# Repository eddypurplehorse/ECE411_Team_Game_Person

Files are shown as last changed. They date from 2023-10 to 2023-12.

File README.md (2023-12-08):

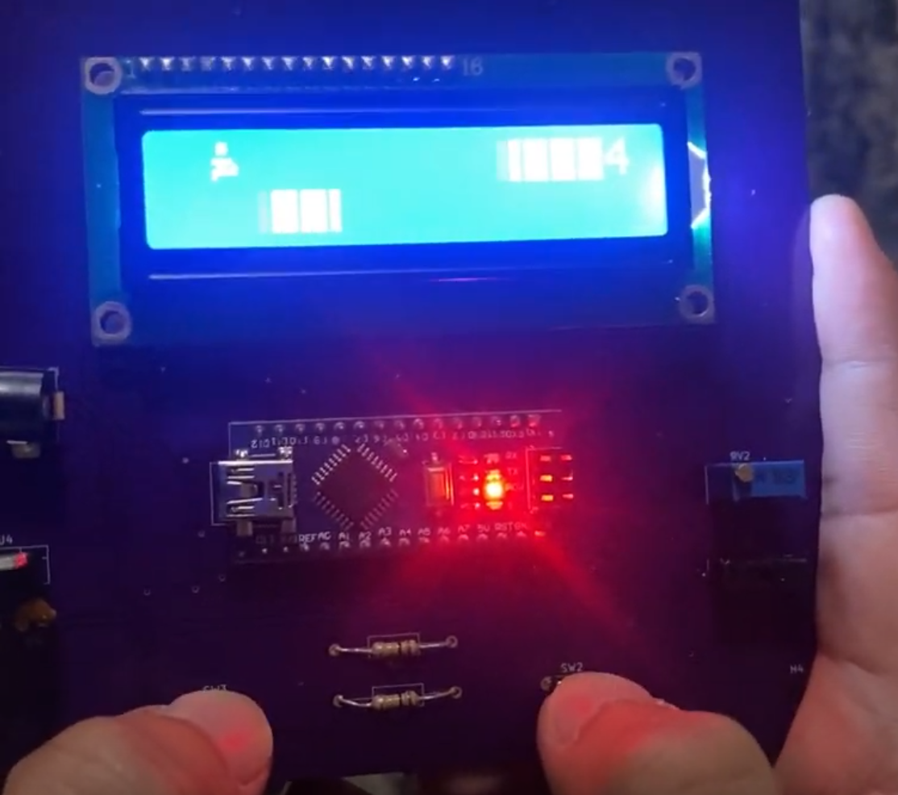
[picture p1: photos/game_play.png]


# ECE 411 Team 10 - Project LCD GAME 

Members:
* Alexandra G
* Eduardo S
* Paul C
* Sam H

## Project
A cheap and fun portable game!

## License
This project is licensed under the term of the GNU General Public V3.0 License  
and the CERN Open Hardware License V2.0 License

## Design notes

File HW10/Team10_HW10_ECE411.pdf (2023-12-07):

TEAM 10: Alexandrea G, Eduardo S, Paul C, Sam H email: guzman8@pdx.edu, eduardo8@pdx.edu, chupaul@pdx.edu, hossein2@pdx.edu

HW 10: Test Plan | Prof. Andrew Greenberg
ECE 411: Industry Design Processes | 12/06/2023

Part 1:

Unit Tests

1. Power Supply Checks:
- Test that the 9V battery outputs a consistent 9V.
- Verify that the 9V-to-5V voltage regulator outputs a stable 5V supply.
- Measure the current draw from the power supply to ensure it's within expected limits.
2. Microcontroller (ATmega328p) Tests:
- Upload a simple sketch to blink an LED to ensure the microcontroller is functioning.
- Test all I/O pins for correct operation by toggling them high and low.
3. LCD Tests:
- Test the LCD display initialization and confirm that characters are correctly displayed.
- Verify SPI bus protocol communication between ATmega328p and the LCD.
- Validate contrast and clear display functions of the LCD.
4. User Interface Components:
- Test that the 10k linear potentiometer properly adjusts the LCD backlight across the entire range.
- Confirm that each push button registers a press and causes an interrupt in the microcontroller.
5. Physical Structure:
- Inspect the housing for structural integrity and fit for the components.
- Ensure the printed circuit board has no shorts or openings and that all solder joints are secure.

Verification Tests

1. Power Connectivity:
- Confirm that the power switch transitions power without interrupting the circuit.
2. Display Operation:
- Test the LCD for correct display of game information upon microcontroller command.
- Verify that the potentiometer effectively dims the LCD backlight.
3. User Interaction:
- Validate that the 'Up' button increases a value on the display, such as score or time.
- Ensure that the 'Down' button decreases a value on the display.
4. Gameplay Experience:
- Simulate a game scenario and verify that all components interact as expected.
- Check that the actuator (LCD) updates in real-time with user input.

Validation Tests

1. System Requirements:
- Validate that the entire system operates continuously under battery power for a set duration.
- Confirm that the user can interact with the game through push buttons and receive visual feedback on the LCD.
- Ensure that the brightness adjustment feature meets the user's need for visibility under different lighting conditions.
2. Performance and Reliability:
- Test that the system can be operated multiple times without failure.
- Validate that the game reacts within acceptable time limits to user input.
3. Aesthetic and Protective Housing:
- Verify that the housing meets the aesthetic design specifications.

Part 2:

Test 1:
Test Author: Alexandrea G, and Sam H.
Test Case Name: | Power Output Verification Test | Test ID #: | PO-VT1
Description: | This test verifies the output of the 9V battery and the 5V regulator output under normal conditions using a multimeter. | Type: | □white box ☑ black box □ ________

Tester Information
| Name of Tester: | Sam H. | Date: | 11/28/2023
| HW/SW Version: | V.1 | Time: | 4:50PM
| Setup: | Fully assembled game device with a 9V battery connected to the power input module and a multimeter set to measure DC voltage.
S T E P | Action | Expected Result | P A S S | F A I L | N / A | Comments
1 | Power up the device using the 9V battery. | LCD screen powers on with welcome message and microcontroller’s red led lights up. | ☑
2 | Measure the output voltage directly from the 9V battery. | The multimeter should read close to 9V, within a tolerance of ±0.5V for the battery output. | ☑
3 | Measure the output voltage from the 9V-to-5V voltage regulator. | The multimeter should read 5V, within a tolerance of ±0.25V for the regulator output. | ☑
4 | Measure the voltage at the power input pin of the microcontroller. | The multimeter should read 5V, within a tolerance of ±0.25V at the microcontroller power input. | ☑
5 | Measure the voltage at the power input of the LCD display. | The multimeter should read 5V, within a tolerance of ±0.25V at the LCD power input. | ☑
6 | Measure the voltage at the | The multimeter should show a variable voltage from 0 to 5V as ☑

| terminals of the 10k linear potentiometer. | the potentiometer is adjusted.
7 | Measure the voltage at the input of each push button when pressed. | The multimeter should read 5V at the push button terminals when pressed and 0V when not pressed. | ☑
| Overall test result: | | ☑ | Test passes 100%.

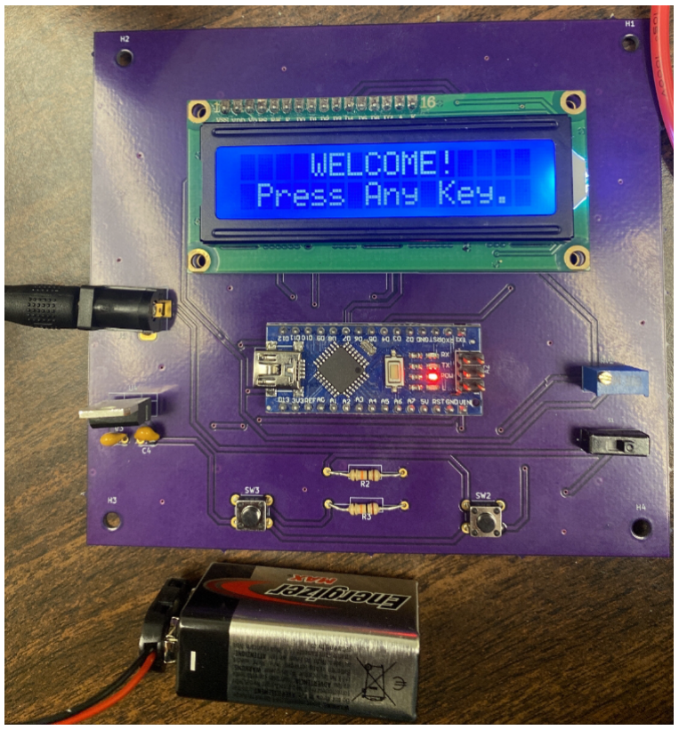
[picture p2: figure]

Figure 1: Test 1 passed.

Test 2:

Test Author: Paul C. and Eduardo S.
Test Case Name: | User Interface Functionality Test | Test ID #: | UI-FT1
Description: | This test verifies the User Interface functionality of the gaming device, specifically testing the LCD display and push-button inputs. | Type: | ☑white box □ black box □ ________

Tester Information
| Name of Tester: | Eduardo S. | Date: | 12/01/2023
| HW/SW Version: | V.1 | Time: | 10:00PM
| Setup: | Arduino Nano with attached LCD display and push buttons setup on the breadboard as per schematic. 9v Battery plugged in. Arduino Nano encoded with game.
S T E P | Action | Expected Result | P A S S | F A I L | N / A | Comments
1 | Power up the device using the 9V battery. | Device powers on without issues. | ☑
2 | Adjust the potentiometer to set the LCD backlight to mid-brightness. | Backlight brightness changes visibly. | ☑
3 | Press the 'Up' button to move the game character up. | Game character moved up on the LCD display. | ☑
4 | Press the 'Down' button to move the game character down. | Game character moved down on the LCD display. | ☑
5 | Check if the LCD updates correctly in response to button presses. | LCD consistently shows correct game character placement in response to button presses. | ☑
| Overall test result: | | ☑ | | | Test passes 100%. A video was recorded of this test being

performed and passing.

The video of the software working can be found here. (https://drive.google.com/file/d/1STEE0lARFS0cR7oybk-pXLPwNEp8A4RE/view?usp=drive_link)

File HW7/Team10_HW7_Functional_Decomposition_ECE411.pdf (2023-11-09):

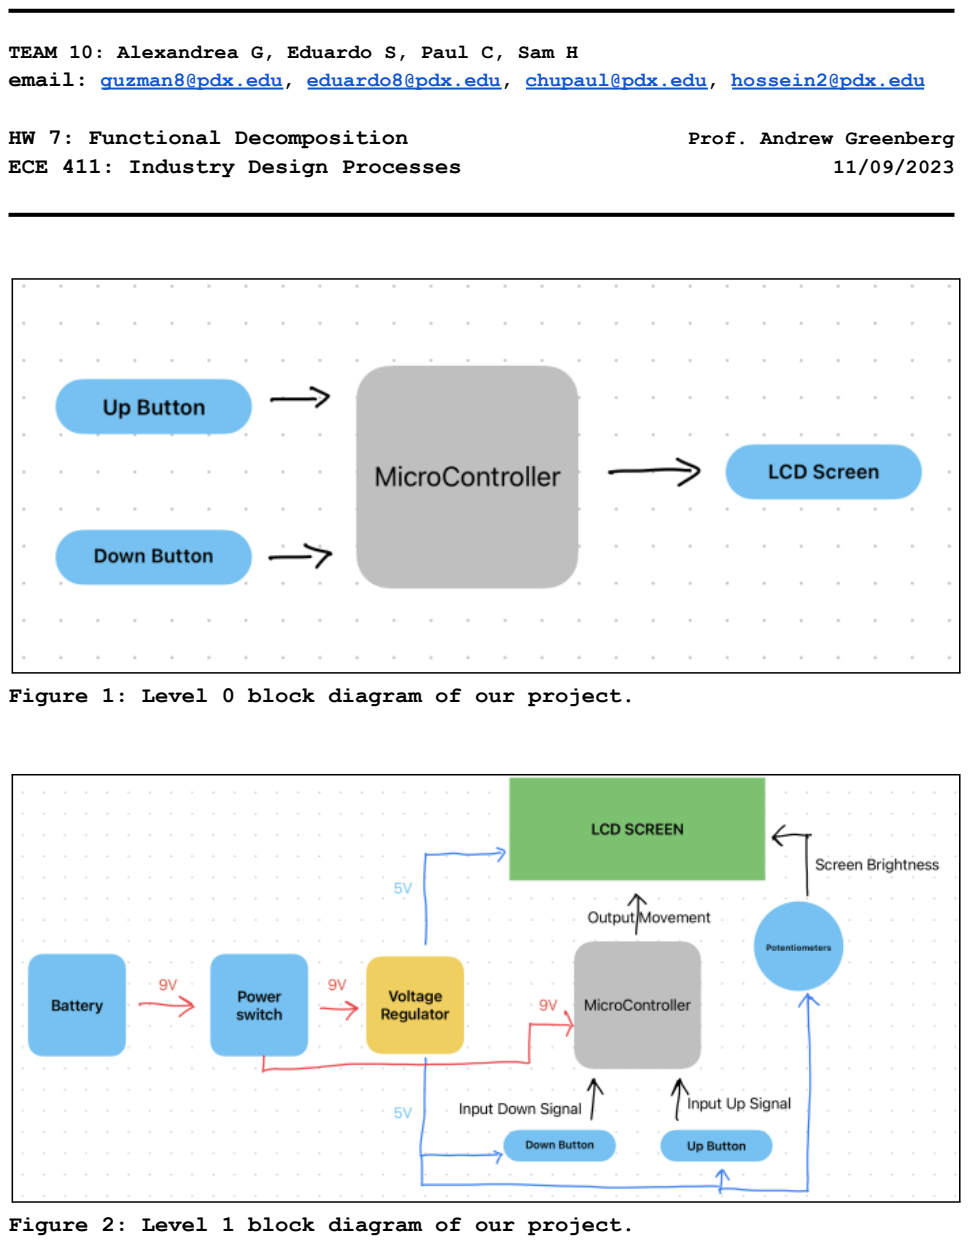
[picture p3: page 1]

TEAM 10: Alexandrea G, Eduardo S, Paul C, Sam H
email: guzman8@pdx.edu, eduardo8@pdx.edu, chupaul@pdx.edu, hossein2@pdx.edu
HW 7: Functional Decomposition | Prof. Andrew Greenberg
ECE 411: Industry Design Processes | 11/09/2023

Figure 1: Level 0 block diagram of our project.

Figure 2: Level 1 block diagram of our project.

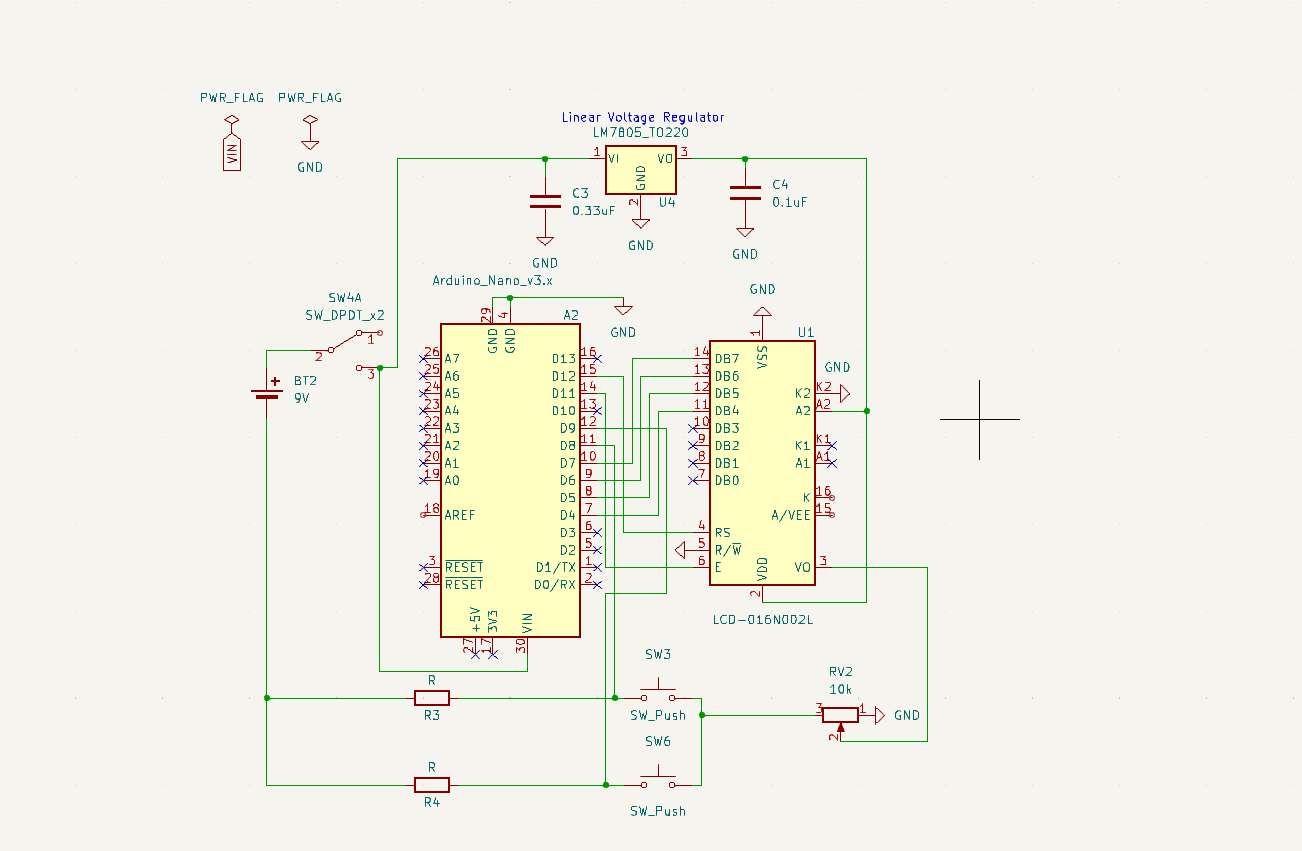
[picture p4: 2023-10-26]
photos/LCD_GAME_SCHEMATIC_V1.png

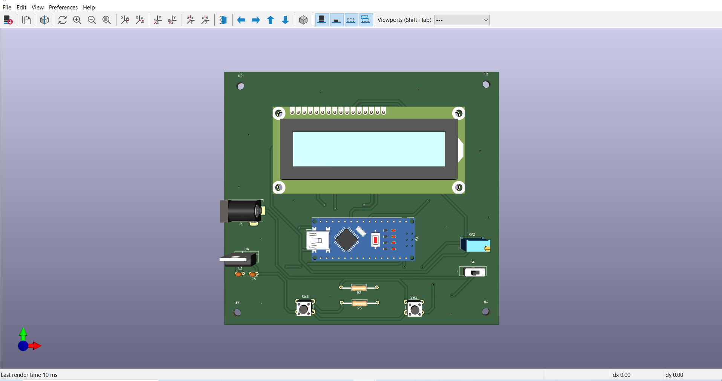
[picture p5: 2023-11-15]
kicad_schematic/V4_LCD_GAME_3D_MODLE_FINAL_VERSION.png

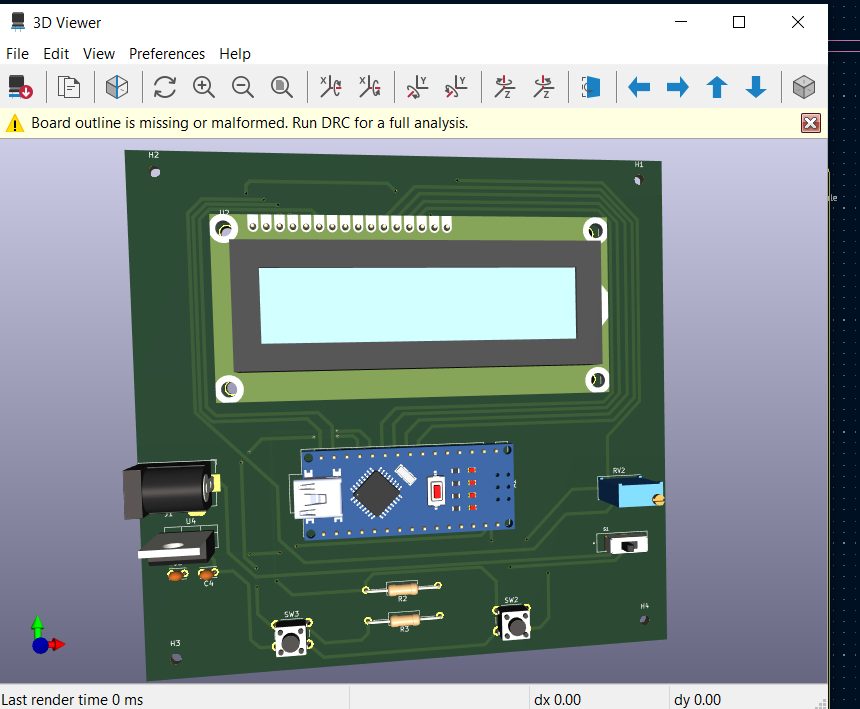
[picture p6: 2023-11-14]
kicad_schematic/V3_LCD_GAME_3D_MODLE.png

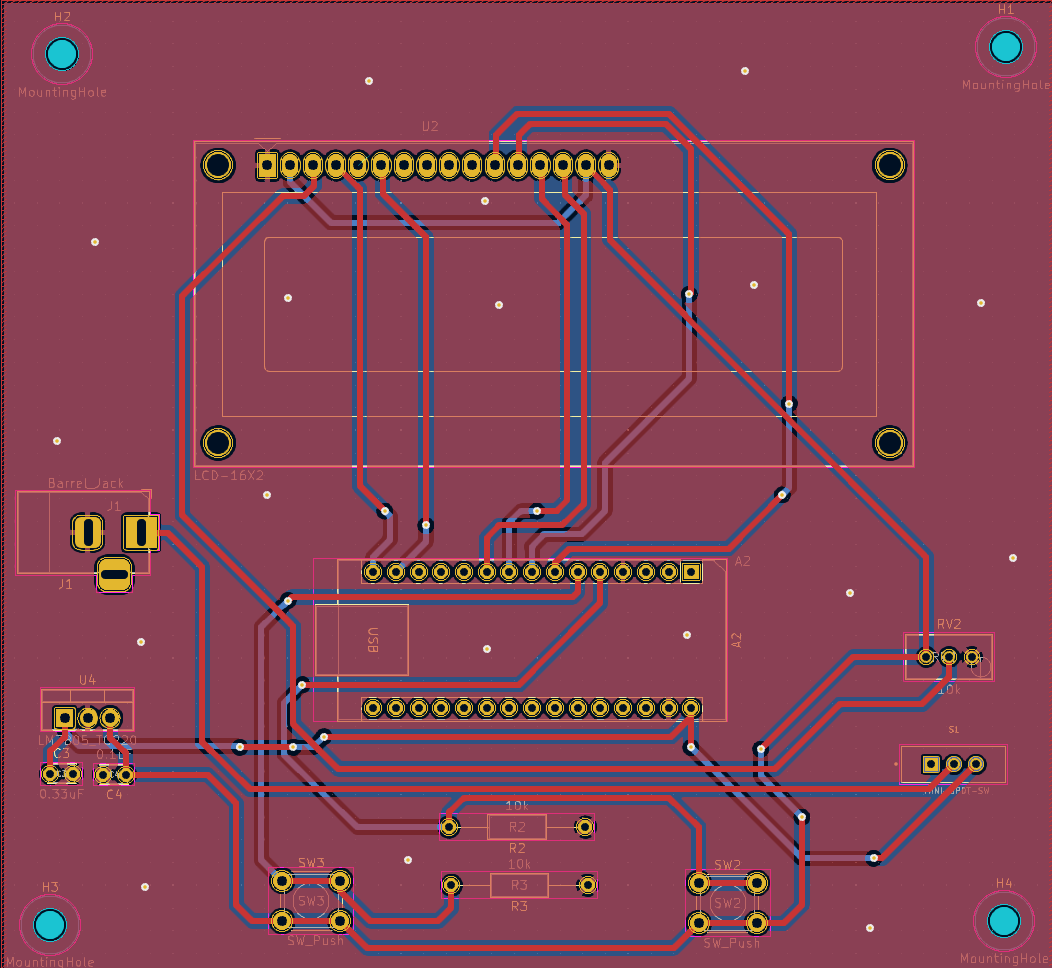
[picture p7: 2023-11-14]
kicad_schematic/V3_LCD_GAME_PCB.png

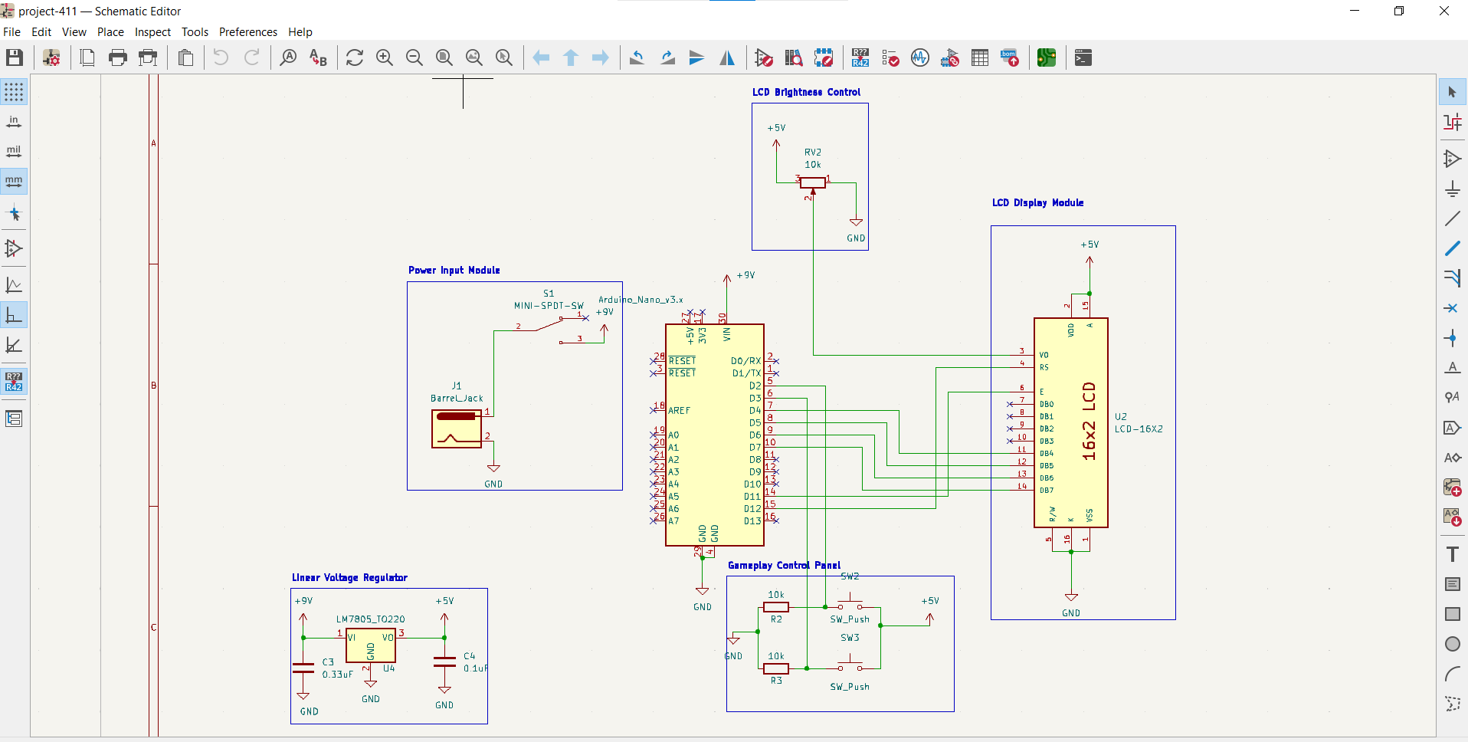
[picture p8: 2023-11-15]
kicad_schematic/V4_LCD_GAME_SCHEMATIC_FINAL_VERSION.png

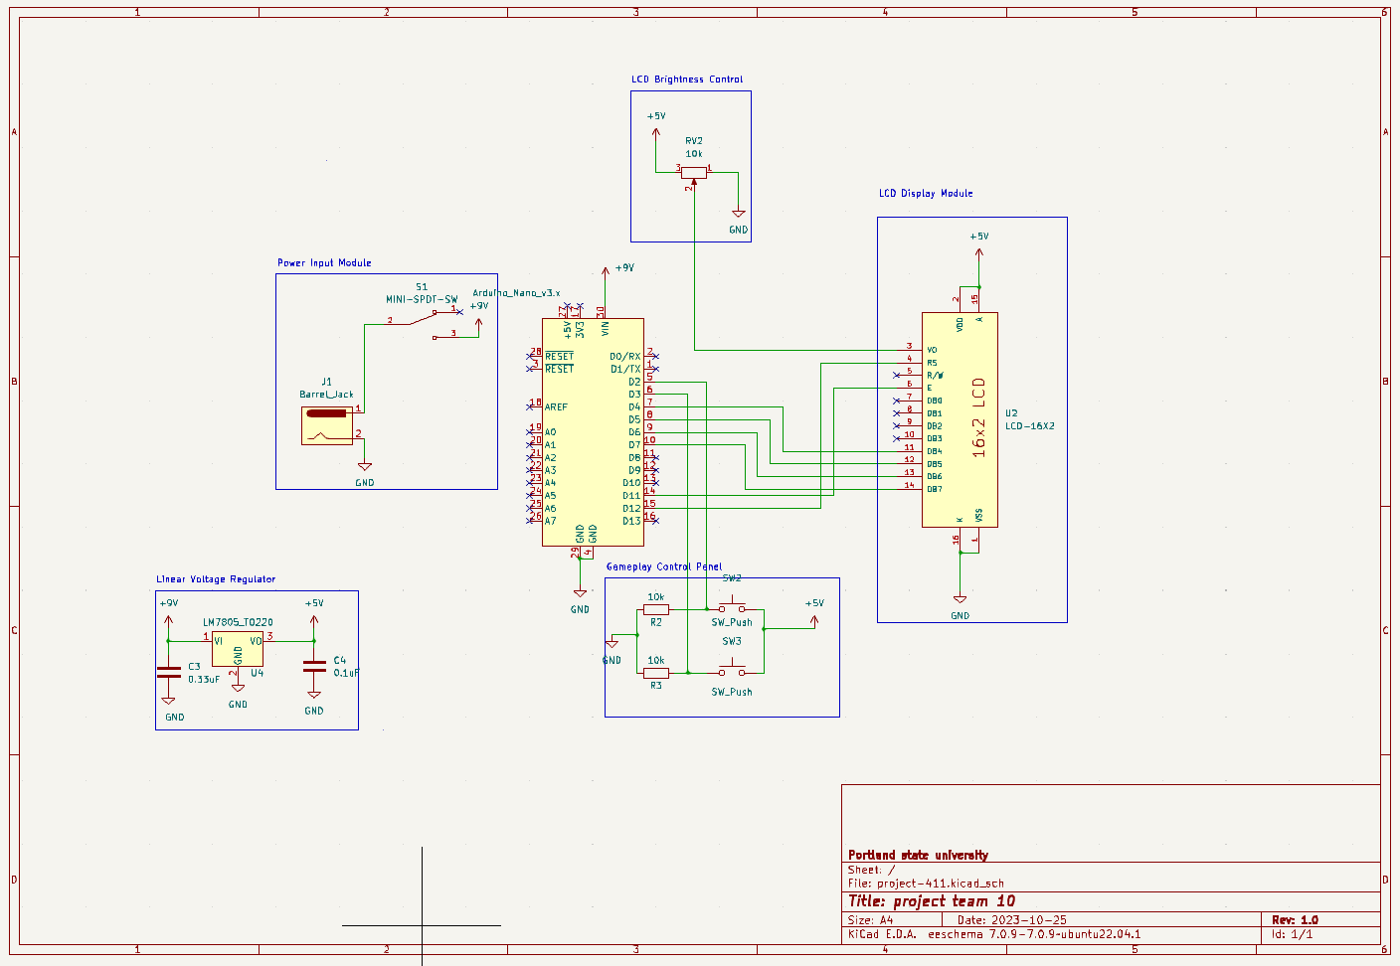
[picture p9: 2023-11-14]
kicad_schematic/V3_LCD_GAME_SCHEMATIC.png

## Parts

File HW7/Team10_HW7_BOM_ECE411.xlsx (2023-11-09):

Bill Of Materials for: [Team 10] [TEAM Gamer]
Last modified: [11/8/2023]
PCB version: [1.0]
BOM revision: [1.0] |  | P/NP | = Place/Not Place (components marked NP are not stuffed on the board)
Cnt | Part References | P/NP | Mfg | Mfg PN | Description | Dist | Dist Part Number | Cost Ea. | Cost Total
1 | A2 | P | LAFVIN | LA020 | Nano 3.0 ATmega328P Microcontroller | Amazon | B07G99NNXL | $6.66 | $6.66
1 | C3 | P | KEMET | C322C334Z5U5TA | 0.33uF capacitor | Digi-Key | 399-9808-ND | $0.44 | $0.44
1 | C4 | P | KEMET | C317C104M5U5TA7301 | 0.1 uF capacitor | Digi-Key | 399-9866-1-ND | $0.32 | $0.32
1 | J1 | P | AiTrip | DC005 | 3 Pin DC Power Connector PCB Mount Female Plug Jack | Amazon | B081DYQSC9 | $0.30 | $0.30
2 | R2, R3 | P | BOJACK | BO-RST01 | 10k Ohm Resistors | Amazon | B07PGHP69F | $0.04 | $0.08
1 | RV2 | P | Amphenol Piher Sensing Systems | PT10MV10-103A2020-E-S | 10k Linear Potentiometer | Digi-Key | 1993-1066-ND | $0.76 | $0.76
1 | S1 | P | CHANZON | SS12D00G | SPDT Mini Micro Slide Switch, 2 Position | Amazon | B09R42XQTB | $0.30 | $0.30
2 | SW2, SW3 | P | SparkFun Electronics | COM-10302 | 4 Pin Pushbuttons | Digi-Key | 1568-1332-ND | $0.54 | $1.08
1 | U2 | P | ‎HiLetgo | HD44780 1602 | 16x2 Liquid Crystal Display | Digi-Key | 4411-CN0293-ND | $7.40 | $7.40
1 | U4 | P | STMicroelectronics | L7805CV | 9V-to-5V 1.5A Linear Voltage Regulator | Adafruit | 2164 | $0.75 | $0.75
1 | N/A | NP | Energizer | E301591600 | 9 Volt Alkaline Batteries | Amazon | B00IA8M42G | $3.34 | $3.34
1 | N/A | P | Bud Industries | HH-3635 | 9V Battery Holder | Digi-Key | 377-2682-ND | $3.50 | $3.50
25 | N/A | P | Global Specialties | WK-3 | Jumper Wires, various sizes | Digi-Key | BKWK-3-ND | $0.07 | $1.75
 |  |  |  |  |  |  |  | TOTAL: | $26.68
VERSION INFO
Rev | Date | Notes
1.0r0 | 2023-11-08 | Initial BOM. Final chosen parts used in the prototype.

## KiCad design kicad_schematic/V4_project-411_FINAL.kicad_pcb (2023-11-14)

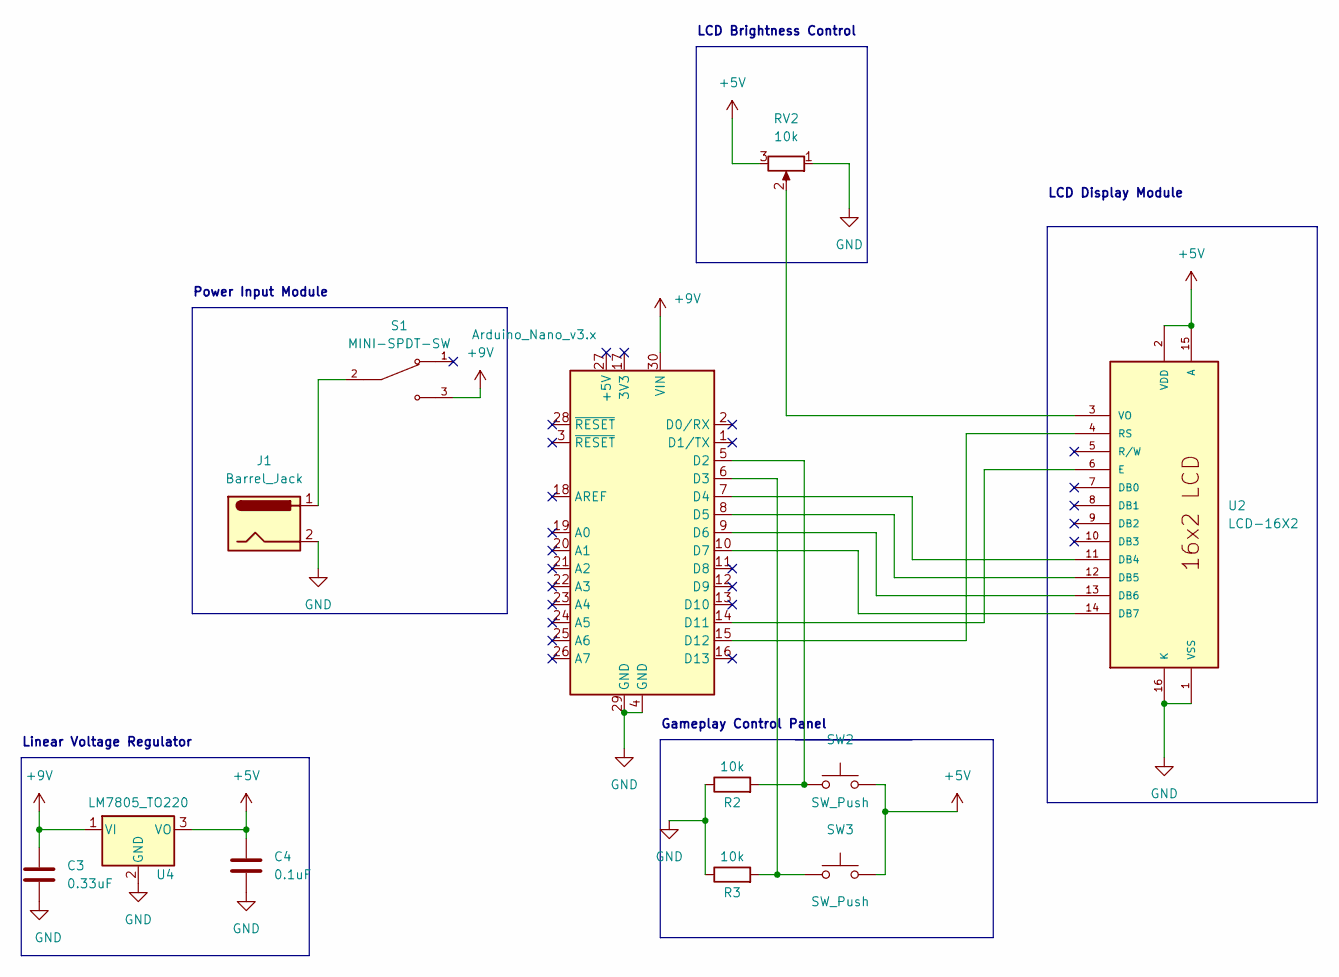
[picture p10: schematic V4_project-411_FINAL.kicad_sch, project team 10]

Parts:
A2: Arduino_Nano_v3.x; Arduino_Nano
C3: 0.33uF; C_Disc_D3.0mm_W2.0mm_P2.50mm
C4: 0.1uF; C_Disc_D3.0mm_W2.0mm_P2.50mm
J1: Barrel_Jack; BarrelJack_Horizontal
R2, R3: 10k; R_Axial_DIN0207_L6.3mm_D2.5mm_P15.24mm_Horizontal
RV2: 10k; Potentiometer_Bourns_3296W_Vertical
S1: MINI-SPDT-SW; SW_MINI-SPDT-SW; PARTREV C
SW2, SW3: SW_Push; SW_PUSH_6mm_H5mm
U2: LCD-16X2; WC1602A; PARTREV N/A
U4: LM7805_TO220; TO-220-3_Vertical

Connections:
+5V: C4.1, RV2.3, SW2.2, SW3.2, U2.2 (VDD), U2.15 (A), U4.3 (VO)
+9V: A2.30 (VIN), C3.1, S1.3, U4.1 (VI)
GND: A2.4 (GND), A2.29 (GND), C3.2, C4.2, J1.2, R2.1, R3.1, RV2.1, U2.1 (VSS), U2.5 (R/W), U2.16 (K), U4.2 (GND)
unnamed: A2.5 (D2), R2.2, SW2.1
unnamed: A2.6 (D3), R3.2, SW3.1
unnamed: A2.7 (D4), U2.11 (DB4)
unnamed: A2.8 (D5), U2.12 (DB5)
unnamed: A2.9 (D6), U2.13 (DB6)
unnamed: A2.10 (D7), U2.14 (DB7)
unnamed: A2.14 (D11), U2.6 (E)
unnamed: A2.15 (D12), U2.4 (RS)
unnamed: J1.1, S1.2
unnamed: RV2.2, U2.3 (VO)

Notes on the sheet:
Gameplay Control Panel
Power Input Module
LCD Brightness Control
LCD Display Module
Linear Voltage Regulator

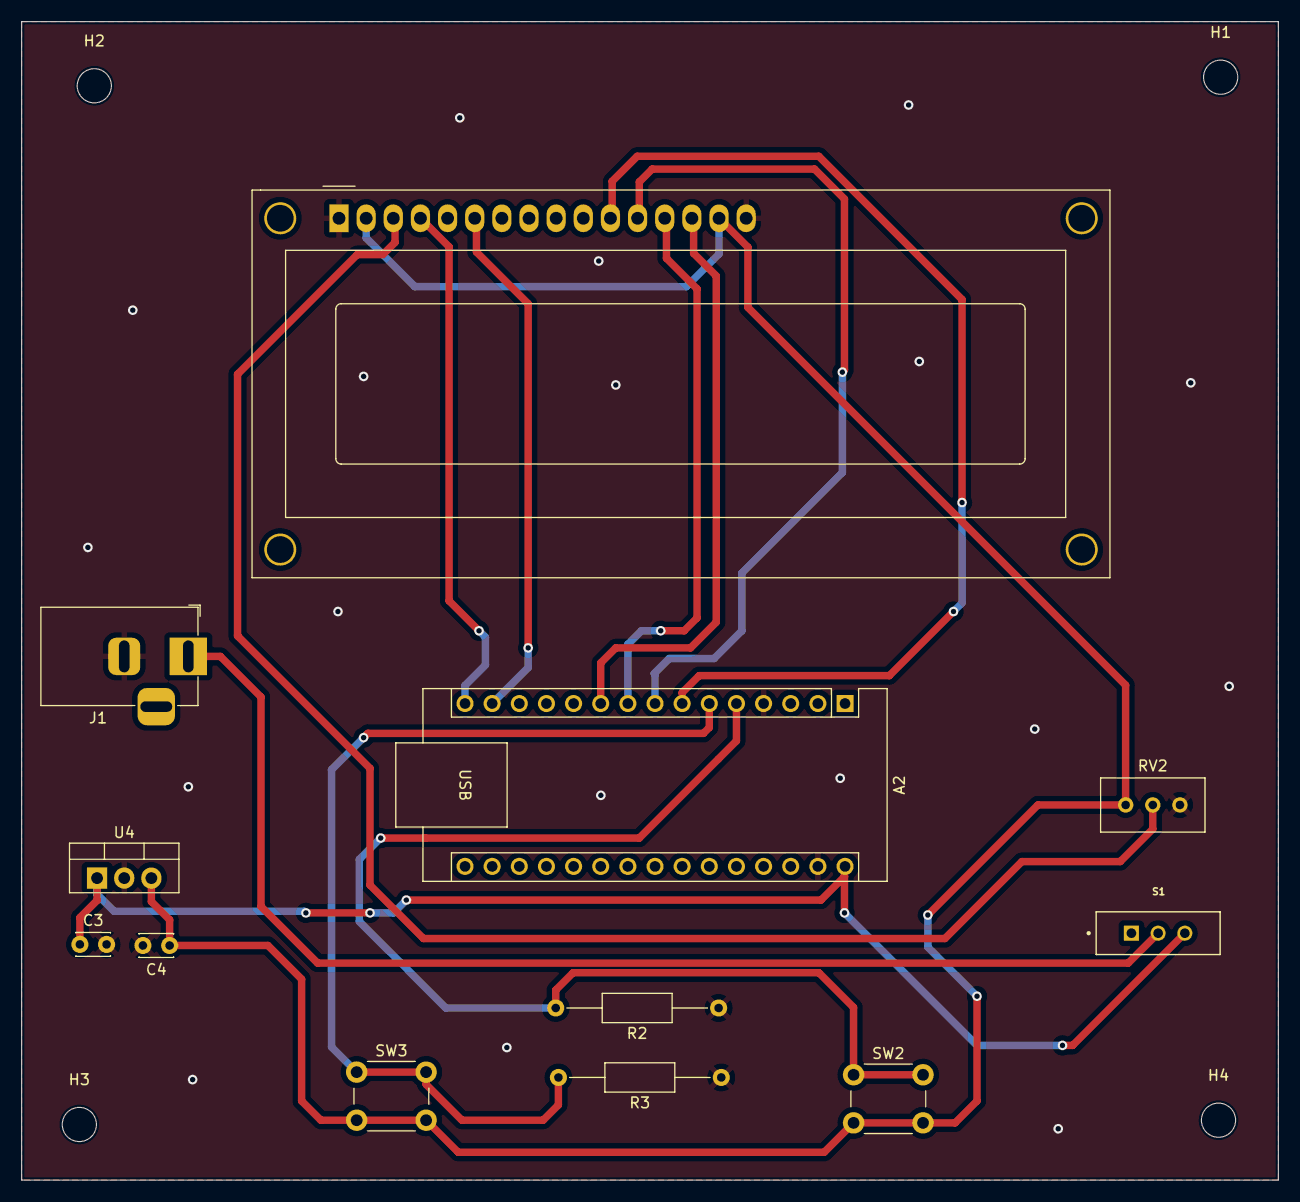
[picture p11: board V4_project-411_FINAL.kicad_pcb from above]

Board: 2 copper layers, 117.6 x 108.4 mm, 16 parts (0 on the bottom side), 13 nets.

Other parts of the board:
H1, H2, H3, H4: MountingHole; MountingHole_3.2mm_M3

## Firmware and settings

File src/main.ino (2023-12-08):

 /**
 * @file    main.ino 
 * @author  Team 10; Alex, Eddy, Paul, Same 
 * @brief   A flappy bird clone game
 * @version 0.1
 * @date    2023-11-11
 * 
 * @copyright Copyright (c) 2023
 * 
 */

#include "graphics.h"
#define TERRAIN_WIDTH 16

char terrain_upper[TERRAIN_WIDTH + 1];
char terrain_lower[TERRAIN_WIDTH + 1];
char player_terrain_overlap[OVERLAP_ARRAY_SIZE];

const int left_button_pin = 9;
const int right_button_pin = 8;
unsigned int game_speed = 400;
unsigned long long total_frames_drawn = 0;


void setup() {
    // GPIO 2
    attachInterrupt(INTERRUPT_ONE, right_button_is_pushed, RISING);
    // GPIO 3
    attachInterrupt(INTERRUPT_TWO, left_button_is_pushed, RISING);
  
    // set up the LCD's number of columns and rows:
    lcd.begin(16, 2);

    // set up button
    pinMode(left_button_pin, INPUT);
    pinMode(right_button_pin, INPUT);

    // set up graphics
    initialize_graphics();

    // HW SW test
    HW_firmware_test();

}

void loop(){
    playing_game = false;
    unsigned int player_position = HERO_POSITION_RUN_LOWER_2;
    static byte new_terrain_type = TERRAIN_EMPTY;
    byte duration_between_terrain = 0;
    unsigned int score = 0;
    bool collision_happened = false;
    game_speed = 400;

    // set up graphics
    initialize_graphics();

    while (!playing_game) {
        draw_home_screen();
        if (left_button_was_pushed || right_button_was_pushed) {
            playing_game = true;
            right_button_was_pushed = false;
            left_button_was_pushed = false;
            lcd.clear();
            break;
        }
        delay(100);
    }
    
    while (playing_game) {

        if (duration_between_terrain == 0) {
            if (new_terrain_type == TERRAIN_EMPTY) {
                new_terrain_type = (random(3) == 0) ? TERRAIN_UPPER_BLOCK : TERRAIN_LOWER_BLOCK;
                duration_between_terrain = 5 + random(10);
            }
            else {
                new_terrain_type = TERRAIN_EMPTY;
                duration_between_terrain = 10 + random(10);
            }
        }

        if (player_position < MIN_HERO_POSITION) {
            player_position = MIN_HERO_POSITION;
        }

        draw_map(terrain_upper, terrain_lower, new_terrain_type, player_terrain_overlap);
        collision_happened = draw_player(player_position, terrain_upper, terrain_lower, score);


        if (collision_happened) {
            break; // game over
        }

        if (total_frames_drawn % 3 == 0) {
          player_position--;
        }

        if (total_frames_drawn % 16 == 0) {
            score++;
            game_speed -= 10;

            if (game_speed < 15) {
              game_speed = 15;
            }
        }

        if (right_button_was_pushed) {
            right_button_was_pushed = false;
            player_position++;

            if (player_position > MAX_HERO_POSITION) {
                player_position = MAX_HERO_POSITION;
            }
        }

        
        delay(game_speed);
        total_frames_drawn++;
        duration_between_terrain--;
    }

    draw_end_game(score);
    delay(2000);
}


void left_button_is_pushed() {
    left_button_was_pushed = true;
}

void right_button_is_pushed() {
    right_button_was_pushed = true;
}

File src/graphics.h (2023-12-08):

#ifndef __GRAPHICS_H__
#define __GRAPHICS_H__

#include <LiquidCrystal.h>

const int rs = 12, en = 11, d4 = 4, d5 = 5, d6 = 6, d7 = 7;
LiquidCrystal lcd(rs, en, d4, d5, d6, d7);

#define FIRST_COLUMN 0
#define TOP_ROW 0
#define BOTTOM_ROW 1

#define INTERRUPT_ONE 0
#define INTERRUPT_TWO 1

#define SPRITE_RUN1 1
#define SPRITE_RUN2 2
#define SPRITE_JUMP 3
#define SPRITE_JUMP_UPPER '.'         // Use the '.' character for the head
#define SPRITE_JUMP_LOWER 4
#define SPRITE_TERRAIN_EMPTY ' '      // User the ' ' character
#define SPRITE_TERRAIN_SOLID 5
#define SPRITE_TERRAIN_SOLID_RIGHT_EDGE 6
#define SPRITE_TERRAIN_SOLID_LEFT_EDGE 7


#define HERO_COLUMN_POSITION 1    // Horizontal position of hero on screen

#define TERRAIN_WIDTH 16
#define TERRAIN_EMPTY 0
#define TERRAIN_LOWER_BLOCK 1
#define TERRAIN_UPPER_BLOCK 2


#define HERO_POSITION_RUN_LOWER_1 1  // Hero is running on lower row (pose 1)
#define HERO_POSITION_RUN_LOWER_2 2  //                              (pose 2)

#define HERO_POSITION_JUMP_1 3       // Starting a jump
#define HERO_POSITION_JUMP_2 4       // Half-way up
#define HERO_POSITION_JUMP_3 5       // Jump is on upper row

#define MIN_HERO_POSITION 2
#define MAX_HERO_POSITION 5

#define OVERLAP_ARRAY_SIZE 4
#define OVERLAP_TOP_ROW_INDEX 0
#define OVERLAP_BOTTOM_ROW_INDEX 1
#define OVERLAP_TERMINATING_CHAR_INDEX 2


extern char terrain_upper[TERRAIN_WIDTH + 1];
extern char terrain_lower[TERRAIN_WIDTH + 1];
extern char player_terrain_overlap[OVERLAP_ARRAY_SIZE]; 
bool left_button_was_pushed = false;
bool right_button_was_pushed = false;
bool playing_game = false;

void initialize_graphics() {
    static byte graphics[] = {
        // Run position 1
        B01100,
        B01100,
        B00000,
        B01110,
        B11100,
        B01100,
        B11010,
        B10011,
        // Run position 2
        B01100,
        B01100,
        B00000,
        B01100,
        B01100,
        B01100,
        B01100,
        B01110,
        // Jump
        B01100,
        B01100,
        B00000,
        B11110,
        B01101,
        B11111,
        B10000,
        B00000,
        // Jump lower
        B11110,
        B01101,
        B11111,
        B10000,
        B00000,
        B00000,
        B00000,
        B00000,
        // Ground
        B11111,
        B11111,
        B11111,
        B11111,
        B11111,
        B11111,
        B11111,
        B11111,
        // Ground right
        B00011,
        B00011,
        B00011,
        B00011,
        B00011,
        B00011,
        B00011,
        B00011,
        // Ground left
        B11000,
        B11000,
        B11000,
        B11000,
        B11000,
        B11000,
        B11000,
        B11000,
    };

    // Skip using character 0, this allows lcd.print() to be used to
    // quickly draw multiple characters
    for (int i = 0; i < 7; i++) {
        lcd.createChar(i + 1, &graphics[i * 8]);
    }
   for (int i = 0; i < TERRAIN_WIDTH; i++) {
        terrain_upper[i] = SPRITE_TERRAIN_EMPTY;
        terrain_lower[i] = SPRITE_TERRAIN_EMPTY;
   }
   for (int i = 0; i < 3; i++) {
      player_terrain_overlap[i] = SPRITE_TERRAIN_EMPTY;
   }

   player_terrain_overlap[OVERLAP_TERMINATING_CHAR_INDEX] = '\0';
}

void draw_home_screen() {
    lcd.clear();
    lcd.setCursor(FIRST_COLUMN, TOP_ROW);
    lcd.print("    WELCOME!    ");
    lcd.setCursor(FIRST_COLUMN, BOTTOM_ROW);
    lcd.print(" Press Any Key. ");
}

void draw_end_game(unsigned int score) {
    // will be displayed on screen
    char score_result[TERRAIN_WIDTH + 1] = "   SCORE = ";

    // how many bytes are needed to represent the score
    byte digits = (score > 9999) ? 5 : (score > 999) ? 4 : (score > 99) ? 3 : (score > 9) ? 2 : 1;

    // take the original string and insert and EOS character 
    // needed for when we print it to the LCD
    score_result[16-digits] = '\0';

    // draw top row
    lcd.clear();
    lcd.setCursor(FIRST_COLUMN, TOP_ROW);
    lcd.print("   GAME OVER    ");

    // draw bottom row
    lcd.setCursor(FIRST_COLUMN, BOTTOM_ROW);
    // first draw the score display
    lcd.print(score_result);
    // set the cursor to point to the starting index that contains the score val
    lcd.setCursor(16 - digits, BOTTOM_ROW);
    // print the score
    lcd.print(score);
}

bool draw_player(byte position, char *terrain_upper, char *terrain_lower, unsigned int score) {
    byte player_sprite_lower = SPRITE_TERRAIN_EMPTY;
    byte player_sprite_upper = SPRITE_TERRAIN_EMPTY;
    char old_upper_sprite    = terrain_upper[HERO_COLUMN_POSITION];
    char old_lower_sprite    = terrain_lower[HERO_COLUMN_POSITION];
    bool collision_happpened = false;

    switch (position) {
    
        case HERO_POSITION_RUN_LOWER_1:
            player_sprite_lower = SPRITE_RUN1;
            break;

        case HERO_POSITION_RUN_LOWER_2:
            player_sprite_lower = SPRITE_RUN2;
            break;

        case HERO_POSITION_JUMP_1:
            player_sprite_lower = SPRITE_JUMP;
            break;
        
        case HERO_POSITION_JUMP_2:
            player_sprite_upper = SPRITE_JUMP_UPPER;
            player_sprite_lower = SPRITE_JUMP_LOWER;
            break;

        case HERO_POSITION_JUMP_3:
            player_sprite_upper = SPRITE_JUMP;
            break;
        
        default:
            break;
    }

    if (player_sprite_upper != ' ') {
        // attach player
        terrain_upper[HERO_COLUMN_POSITION] = player_sprite_upper;

        if (old_upper_sprite != SPRITE_TERRAIN_EMPTY) {
            collision_happpened = true;
        }
    }

    if (player_sprite_lower != ' ') {
        // attach player
        terrain_lower[HERO_COLUMN_POSITION] = player_sprite_lower;

        if (old_lower_sprite != SPRITE_TERRAIN_EMPTY) {
            collision_happpened = true;
        }
    }

    byte digits = (score > 9999) ? 5 : (score > 999) ? 4 : (score > 99) ? 3 : (score > 9) ? 2 : 1;

    terrain_upper[TERRAIN_WIDTH] = '\0';
    terrain_lower[TERRAIN_WIDTH] = '\0';

    // print top row; i.e. player, terrain, score
    char temp = terrain_upper[TERRAIN_WIDTH - digits]; // temp save the sprite before the start of score
    terrain_upper[TERRAIN_WIDTH - digits] = '\0'; // overwrite sprite we just saved in temp 
    lcd.setCursor(FIRST_COLUMN, TOP_ROW);
    lcd.print(terrain_upper);
    terrain_upper[TERRAIN_WIDTH - digits] = temp; // unco the changes made by temp
    lcd.setCursor(TERRAIN_WIDTH - digits, TOP_ROW);
    lcd.print(score);

    // print bottom row
    lcd.setCursor(FIRST_COLUMN, BOTTOM_ROW);
    lcd.print(terrain_lower);

    // now that hero is drawn, reattached old terrain sprite so that the map function still works
    terrain_upper[HERO_COLUMN_POSITION] = old_upper_sprite;
    terrain_lower[HERO_COLUMN_POSITION] = old_lower_sprite;

    return collision_happpened;
}
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

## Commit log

2023-10-24 initial code
    the code so is a hello blink and hello world program. It's simply for ensuring the hardware is set up correctly.
    [main.ino]
2023-10-26 init project schematic
    [LCD_GAME.kicad_sch]
2023-10-31 picture - first working project prototype
2023-11-01 schematic version 2
2023-11-09 current pcb progress
    [LCD_GAME.kicad_sch, project-105d.kicad_pcb]
2023-11-11 start of API
    button detection function using HW interrupt. Basic player sprite generator function
2023-11-11 kicad V3
    [project-105d.kicad_pcb, project-411.kicad_pcb, project-411.kicad_sch]
2023-11-14 updated kicad schematic version steam
    [V2_project-411.kicad_pcb, V2_project-411.kicad_sch, V3_project-411_FINAL.kicad_pcb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]
2023-11-14 renamed v1 schematic
2023-11-15 final kicad version
    [V4_project-411_FINAL.kicad_pcb, V4_project-411_FINAL.kicad_sch]
2023-12-08 bug fix in init function
    [graphics.h]
